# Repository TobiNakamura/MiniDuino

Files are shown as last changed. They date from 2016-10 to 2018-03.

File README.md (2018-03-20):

# MiniDuino
A minimalist arduino module featuring a ATmega328p, external clock, and 5v regulator with reverse polarity protection. 
Note unite does not have USART <-> USB capability.

# Programming
Connect Bus Pirate (red board) to MiniDuino.
	MISO -> PB4
	MOSI -> PB3
	CLK -> PB5
	CS -> RESET
	GND -> GND

Apply power to the MiniDuino. 
	9 volts -> Vin

Write Program in Arduino (or atmel studio). For pin numbering reference see Arduino_Uno_Rev3-schematic.pdf.
Export compiled hex file from Arduino IDE
	Sketch > Export Compiled Binary

Upload the hex file to MiniDuino using AVRDude
	$ sudo avrdude -c buspirate -P /dev/ttyUSB0 -p atmega328p -F -v -U flash:w:[name of file].hex

# Technical Details
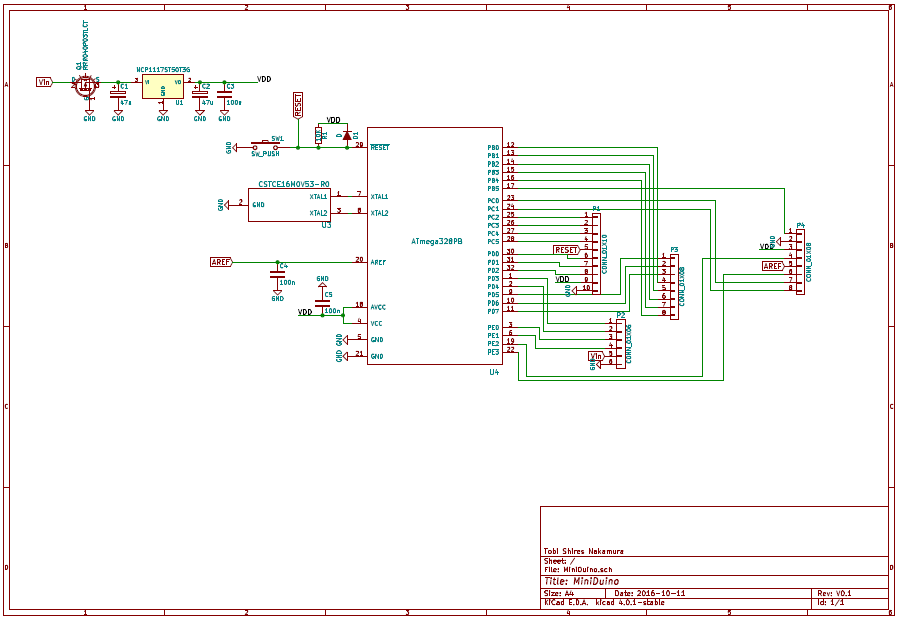
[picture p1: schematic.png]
schematic

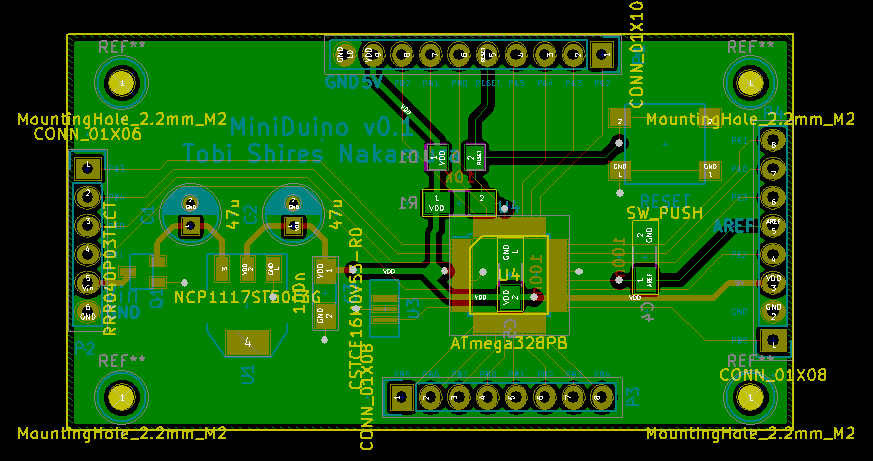
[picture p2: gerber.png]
GERBER


The board was partially constructed to test the input polarity protection (up to 20v), voltage regulator (drop off 5.12v), and reset pin circuit (default pulled to 5v, button press pulls to GND).
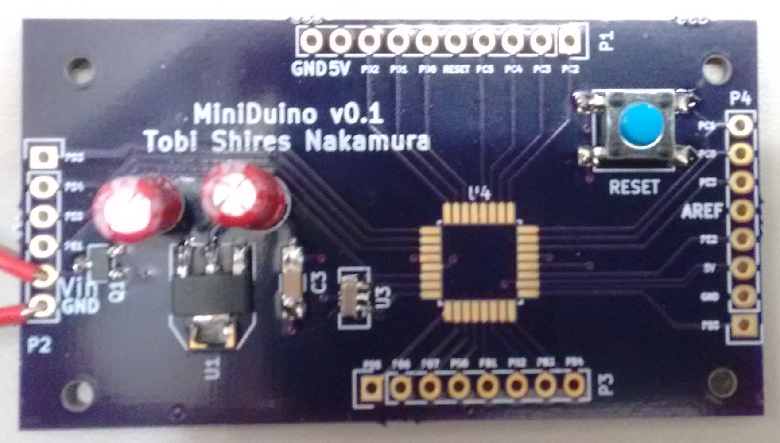
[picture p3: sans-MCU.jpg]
partially constructed

MCU was drag soldered and the first blinky program is flashed. The factory default is for the MCU to use the internal RC oscillator, resulting in a very slow blinky.
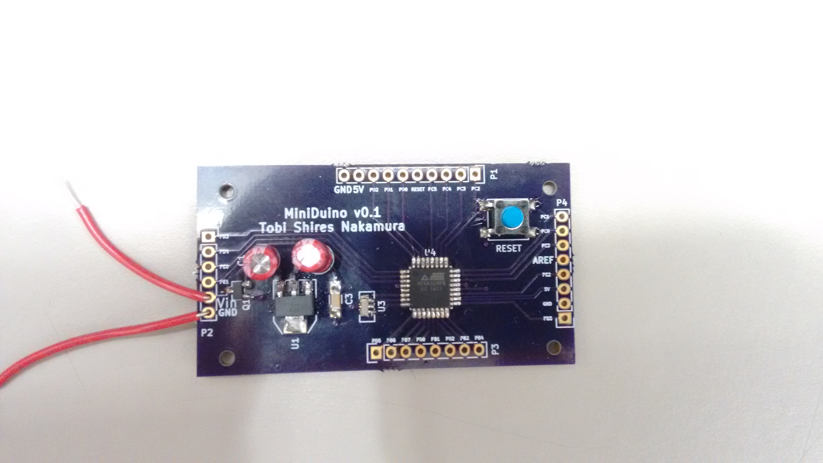
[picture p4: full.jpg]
fully constructed

Using AVRDude, fuse bits CKSEL[0..3] was changed from the default 0010 to 1111 for the external low power crystal oscilator.
avrdude -c usbtiny -p atmega328p -F -v -U lfuse:w:0xFF:m
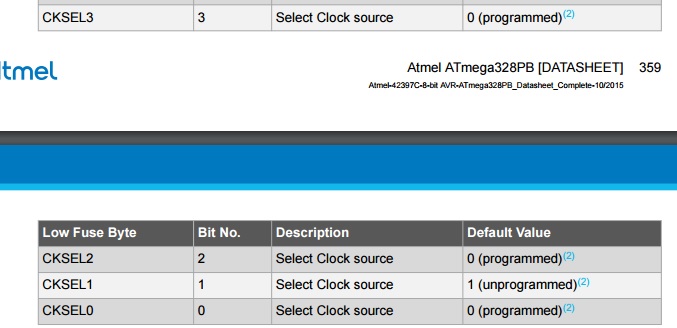
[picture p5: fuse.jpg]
fuse bits

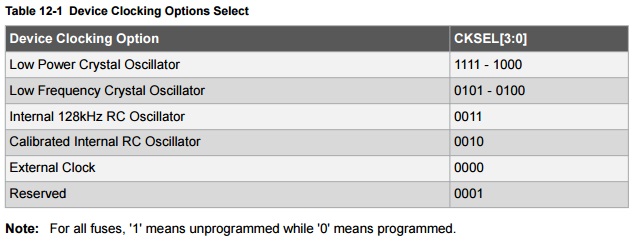
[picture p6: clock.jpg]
clock setting


Channel 1(yellow) is XTAL1, channel 2 (blue is XTAL2). Both waveforms are within spec. Just look at their stability...
clock waveform

There does however seem to be some stray inductance; mostlikely due to my bad soldering.

Done!
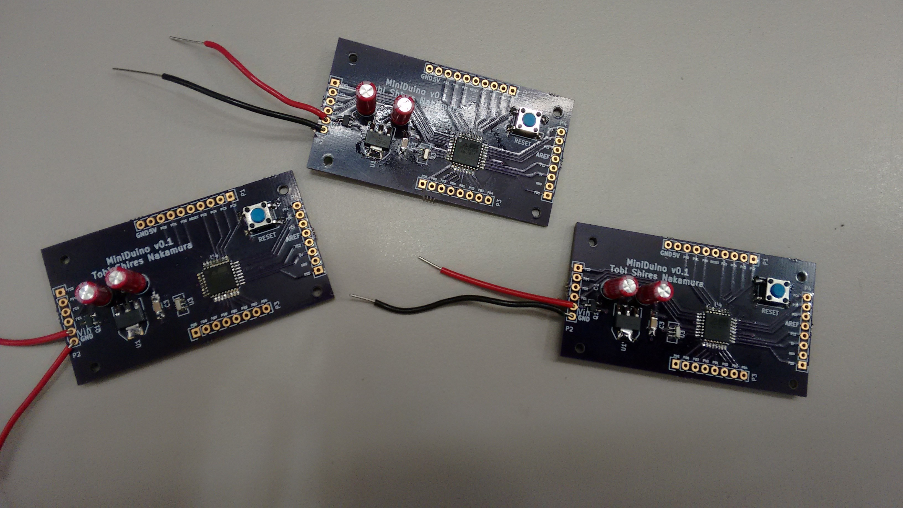
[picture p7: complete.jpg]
done


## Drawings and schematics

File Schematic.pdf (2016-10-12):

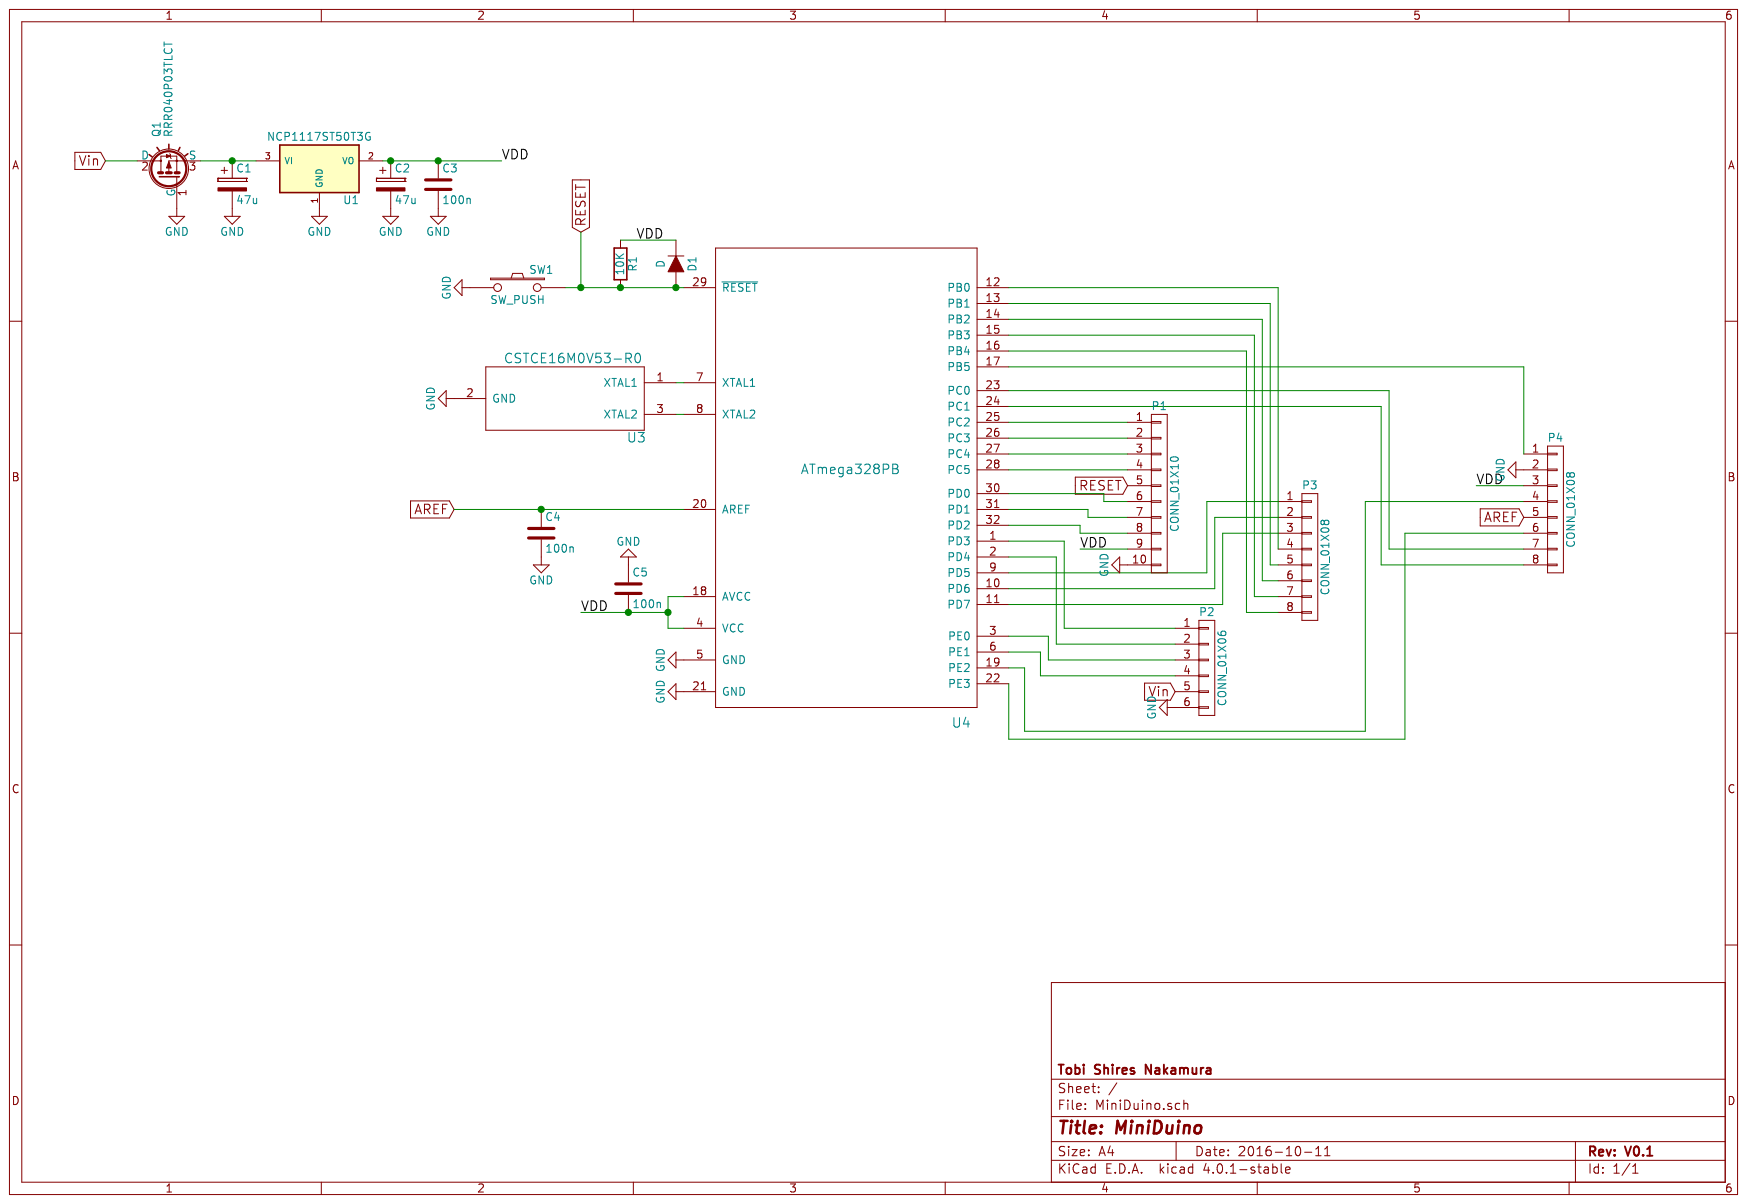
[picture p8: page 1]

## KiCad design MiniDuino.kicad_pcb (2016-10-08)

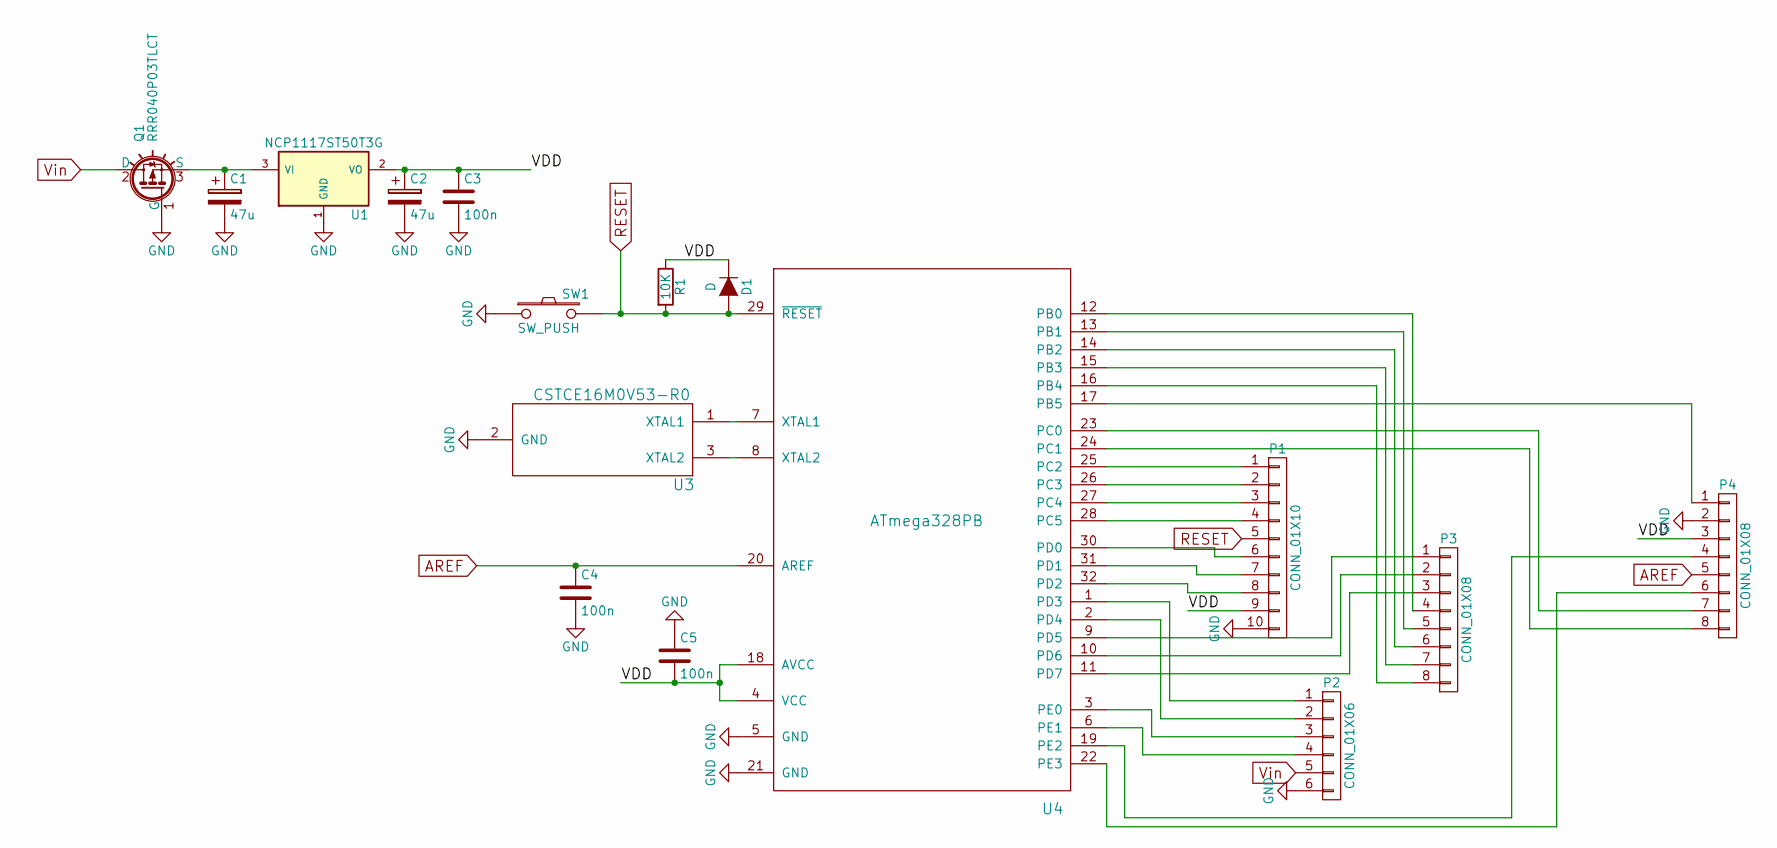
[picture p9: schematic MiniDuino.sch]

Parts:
C1, C2: 47u; C_Radial_D5_L11_P2
C3, C4, C5: 100n; C_1206_HandSoldering
D1: D; SMD-1206_Pol
P1: CONN_01X10; Pin_Header_Straight_1x10
P2: CONN_01X06; Pin_Header_Straight_1x06
P3, P4: CONN_01X08; Pin_Header_Straight_1x08
Q1: RRR040P03TLCT; RRR040P03
R1: 10K; R_1206_HandSoldering
SW1: SW_PUSH; PTS645
U1: NCP1117ST50T3G; SOT-223
U3: CSTCE16M0V53-R0
U4: ATmega328PB; TQFP-32_7x7mm_Pitch0.8mm

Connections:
/VDD: C2.1, C3.1, C5.2, D1.1 (K), P1.9, P4.3, R1.1, U1.2 (VO), U4.4 (VCC), U4.18 (AVCC)
AREF: C4.1, P4.5, U4.20 (AREF)
GND: C1.2, C2.2, C3.2, C4.2, C5.1, P1.10, P2.6, P4.2, Q1.1 (G), SW1.1, U1.1 (GND), U3.2 (GND), U4.5 (GND), U4.21 (GND); also elsewhere on the board
unnamed: C1.1, Q1.3 (S), U1.3 (VI)
unnamed: P1.1, U4.25 (PC2)
unnamed: P1.2, U4.26 (PC3)
unnamed: P1.3, U4.27 (PC4)
unnamed: P1.4, U4.28 (PC5)
unnamed: P1.6, U4.30 (PD0)
unnamed: P1.7, U4.31 (PD1)
unnamed: P1.8, U4.32 (PD2)
unnamed: P2.1, U4.1 (PD3)
unnamed: P2.2, U4.2 (PD4)
unnamed: P2.3, U4.3 (PE0)
unnamed: P2.4, U4.6 (PE1)
unnamed: P3.1, U4.9 (PD5)
unnamed: P3.2, U4.10 (PD6)
unnamed: P3.3, U4.11 (PD7)
unnamed: P3.4, U4.12 (PB0)
unnamed: P3.5, U4.13 (PB1)
unnamed: P3.6, U4.14 (PB2)
unnamed: P3.7, U4.15 (PB3)
unnamed: P3.8, U4.16 (PB4)
unnamed: P4.1, U4.17 (PB5)
unnamed: P4.4, U4.19 (PE2)
unnamed: P4.6, U4.22 (PE3)
unnamed: P4.7, U4.23 (PC0)
unnamed: P4.8, U4.24 (PC1)
unnamed: U3.1 (XTAL1), U4.7 (XTAL1)
unnamed: U3.3 (XTAL2), U4.8 (XTAL2)
RESET: D1.2 (A), P1.5, R1.2, SW1.2, U4.29 (~RESET); also elsewhere on the board
Vin: P2.5, Q1.2 (D)

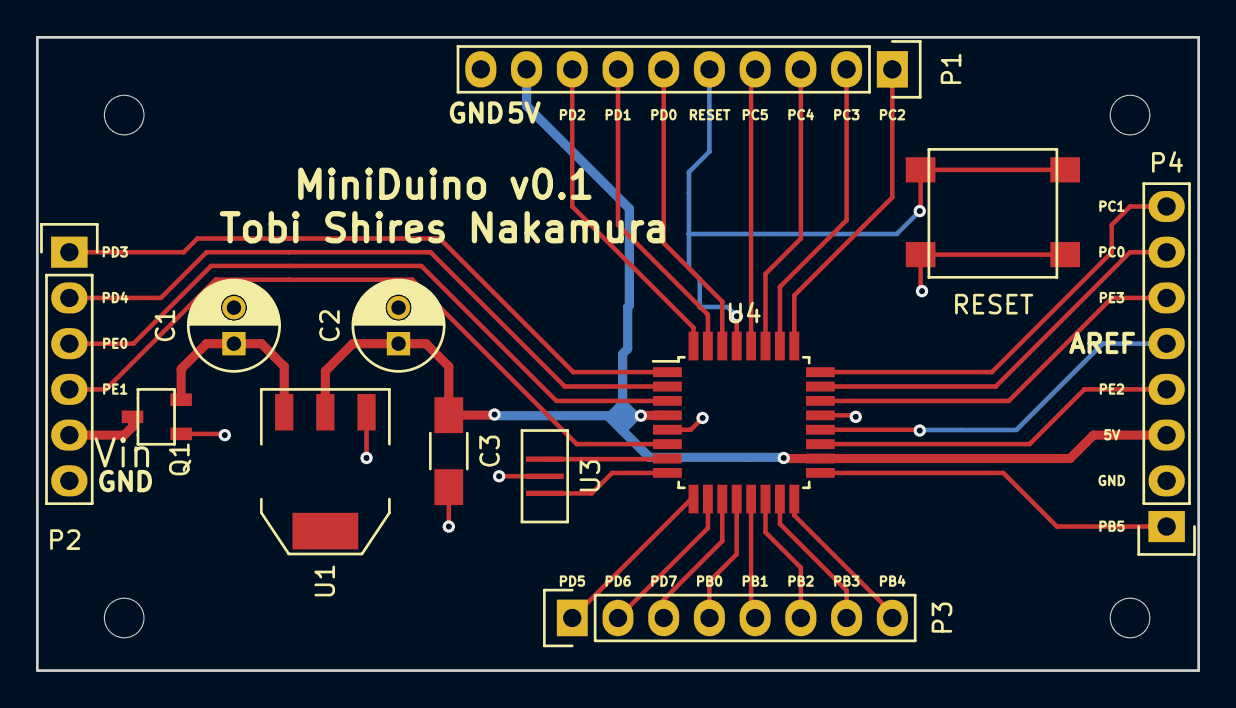
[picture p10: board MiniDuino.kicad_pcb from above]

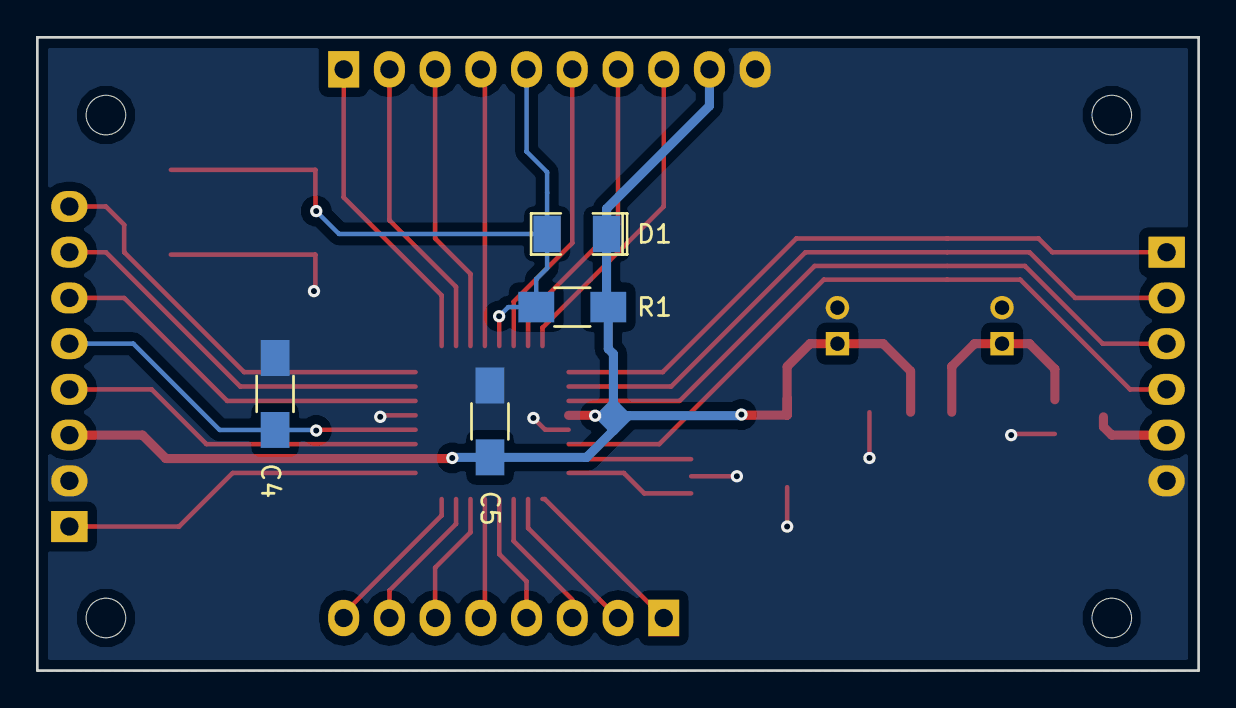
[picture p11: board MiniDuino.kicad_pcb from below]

Board: 2 copper layers, 64.5 x 35.2 mm, 16 parts (4 on the bottom side), 32 nets.

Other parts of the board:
RESET: SW_PUSH; PTS645

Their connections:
GND: RESET.1; also elsewhere on the board
RESET: RESET.2; also elsewhere on the board

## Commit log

2016-10-08 initial commit for version 0.1
    [MiniDuino-B.Cu.gbr, MiniDuino-B.Mask.gbr, MiniDuino-B.SilkS.gbr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]
2016-10-12 added readme and img for partially constructed board
2016-10-12 cropped img of partially constructed board
2016-10-23 added readme and images for complete circuit
2016-10-24 added comment about bad soldering and inductance in clock signal
2016-10-24 added image of all 3 completed boards
